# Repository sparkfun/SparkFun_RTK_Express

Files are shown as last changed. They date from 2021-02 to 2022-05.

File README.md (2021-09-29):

SparkFun RTK Express
===========================================================

SparkFun RTK Express (https://www.sparkfun.com/products/18442)

[*SparkFun RTK Express (GPS-18442)*](https://www.sparkfun.com/products/18442)

The SparkFun RTK Express is an easy to use GNSS receiver for centimeter-level positioning. Perfect for surveying, logging, and all types of post processing, this preprogrammed device can also be used for autonomous driving, navigation, asset tracking and any other application where there is a clear view of the sky. The RTK Express can also be used as a base station. With the press of a button, two RTK Expresses can be used to create an RTK system capable of 14mm horizontal positional accuracy. The built-in Bluetooth® connection via an ESP32 WROOM enables the user to use the RTK Express with their choice of GIS application on a phone or tablet. The built in battery allows for over five hours of field use and is compatible with common USB battery banks.

Repository Contents
-------------------

* **/Enclosure** - gcode for enclosure milling
* **/Graphics** - Bitmaps for the display
* **/Hardware** - Eagle files
* **/Overlay** - Design files for the adhesive membrane overlay

Documentation
--------------

* **[Hookup Guide](https://learn.sparkfun.com/tutorials/sparkfun-rtk-express-hookup-guide)** - Hookup guide for the SparkFun RTK Express.

License Information
-------------------

This product is _**open source**_!

Various bits of the code have different licenses applied. Anything SparkFun wrote is beerware; if you see me (or any other SparkFun employee) at the local, and you've found our code helpful, please buy us a round!

Please use, reuse, and modify these files as you see fit. Please maintain attribution to SparkFun Electronics and release anything derivative under the same license.

Distributed as-is; no warranty is given.

- Your friends at SparkFun.

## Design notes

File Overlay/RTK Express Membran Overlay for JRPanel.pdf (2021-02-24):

Please find the attached 1:1 PDF and AI files.

Membrane Switch

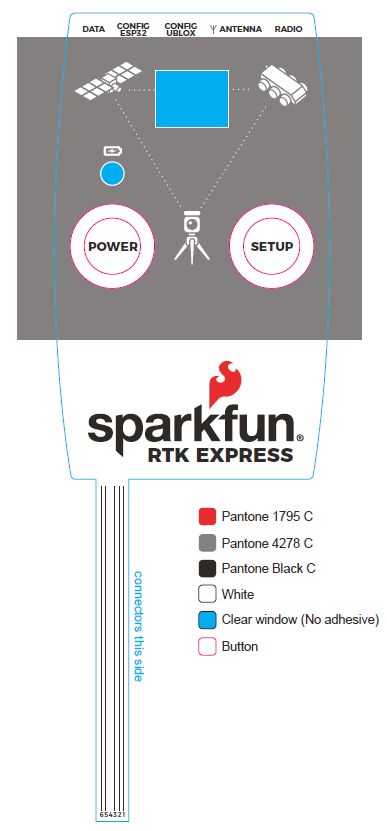
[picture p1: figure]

We need good UV protection as this device will be used outdoors.

Dimensions:
- ~160x80mm

Qty:
- 100pcs

Material:
- PC

Material Surface:
- Glossy Surface

Adhesive:
- We think we need 3M468 but welcome feedback.

Material Thickness:
- We think we need 0.175 but welcome feedback.

Color Quantity:
- 3

Top embossing:
- Yes

LED:
- Qty: 1
- What is the best method to diffuse the LED in a membrane overlay? Do you recommend the material over the LED be lightly painted?
- Color: Red
- Size: 1206

Buttons: (https://www.jrpanel.com/product/)
- Qty: 2
- Type: Die pressing
- Shape: “Flat embossed key”

Ribbon connector:
- Overall width: 6.5mm
- Only 5 conductors are needed

Windows:
- Yes

Cutting Method:
- Mould cutting

No gloss window with matte surface No light color process

No electrostatic shield

Ribbon connector detail:

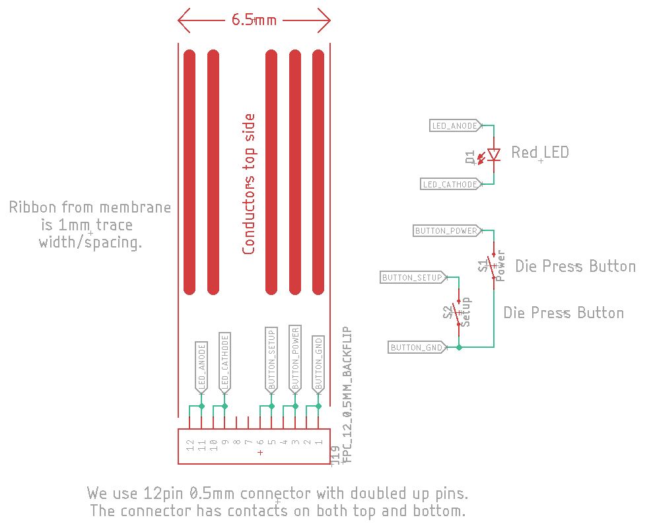
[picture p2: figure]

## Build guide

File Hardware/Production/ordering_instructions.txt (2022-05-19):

panel size, 220x136mm
PCB thickness, 1.6mm
number of layers, 4
controlled impedance, JLC7628
soldermask color, Red
silkscreen color, White
oz copper, 1oz
finish, ENIG
stencils, top+bottom
pcs per panel, 3
min trace width, 0.1778mm / 0.0070in
min drill size, 0.3048mm / 0.0120in
filename to layer stackup 1/2/3/4: GTL, GL2, GL3, GBL

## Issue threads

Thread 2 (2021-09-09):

Sparkfun RTK Express RTCM ver

BeniDodelson, 2021-09-09:
Hi,

I wonder if RTK Express supports RTCM ver 3.2 and/or what ver. it supports?

Tx.

nseidle, 2021-09-09:
See Default interface settings in the [integration manual](https://www.u-blox.com/sites/default/files/ZED-F9P_IntegrationManual_UBX-18010802.pdf)

> RTCM 3.3 is the default input and output protocol

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

BeniDodelson, 2021-09-10:
Tx. Nathan.

Appreciate your help.

Beni.

Beni Dodelson
G.P.Co. Trade Ltd.

20b Ha’Gome St.
POB 4187
Kadima
Israel 6092000

Tel : +972 - (0)54 - 5707979
Fax: +972 – (0) 9 – 8992284
E_mail :  ***@***.***> ***@***.***

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

Closed 2021-09-09.

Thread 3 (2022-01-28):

[sparkfun]RTK Express support

jblee94, 2022-01-28:
hello.

I'd like to ask you questions while using RTK after watching "RTK Express Hookup Guide".

1. What does "Mean" mean in the survey procedure at Base Station?
As a result of the test, if 30 satellites are used and move on to the survey procedure, "Mean" will be lowered to 0.7. (If "Time" is set to 600 seconds via S/W)

2. Configuration settings through serial connection.
Serial access, set "main menu" -> "3) configuration base" -> "3) set required mean 3D standard deviation: 5.000 meters" and then exit "main menu" and check the data in the base mode, and it appears as "waiting for horzacuracy < 2.00 meters".
Here, "waiting for horror <1.00" How can I change this part to a value other than "1.00"?

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

nseidle, 2022-01-31:
Hi,

1) Mean is to [average](https://www.mathsisfun.com/definitions/mean.html) across a set of numbers. On the RTK products, we use the recommended u-blox procedure: we take readings for 60s and until the mean (average) standard deviation is less than 5 meters. Increasing the survey time to 600s will marginally help accuracy of a temperary base, but I don't recommend it. If you need accuracy for your base, use a [fixed base](https://learn.sparkfun.com/tutorials/how-to-build-a-diy-gnss-reference-station/all#affix-your-antenna).

2) Before a survey begins, the RTK firmware waits for the current fix accuracy to be better than 1m. This is to prevent a unit entering survey mode directly from a power on hot start. If a survey begins with poor fix accuracy it will cause the standard mean to be very large, thus causing a survey to fail.

This 1.0m value cannot (currently) be changed and is by design. I am always open to adding more features if you can describe the situation where you need to modify this value.

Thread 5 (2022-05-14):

add another button to the overlay

mzandrew, 2022-05-14:
It would be nice to have an extra button (or two) for the interface.  Something to add the ability to mark multiple types of thing during a single survey (think button "A" for fenceposts vs button "B" for treestumps).  Or could mark the beginning and end of tracks (think press "A"; perambulate one's yard; press "A" again; move to backyard; repeat; end up with two tracks marking out yards).  Button "B" could close file and open another one to further aid in doing complicated surveys.

An extra button or two could also add functionality to various menus.

Looks like there's two spare pins on the connector that could be used, so one button probably wouldn't be a big deal to add (without forgoing the pin doubling or changing the connector type).  Would need to modify the main board to accommodate this of course.

nseidle, 2022-05-14:
Hi! Thanks for the idea contribution. For now we plan to keep the device as simple as possible and leave the user interactions to the tablet or cellphone to record points of interest.

Closed 2022-05-14.

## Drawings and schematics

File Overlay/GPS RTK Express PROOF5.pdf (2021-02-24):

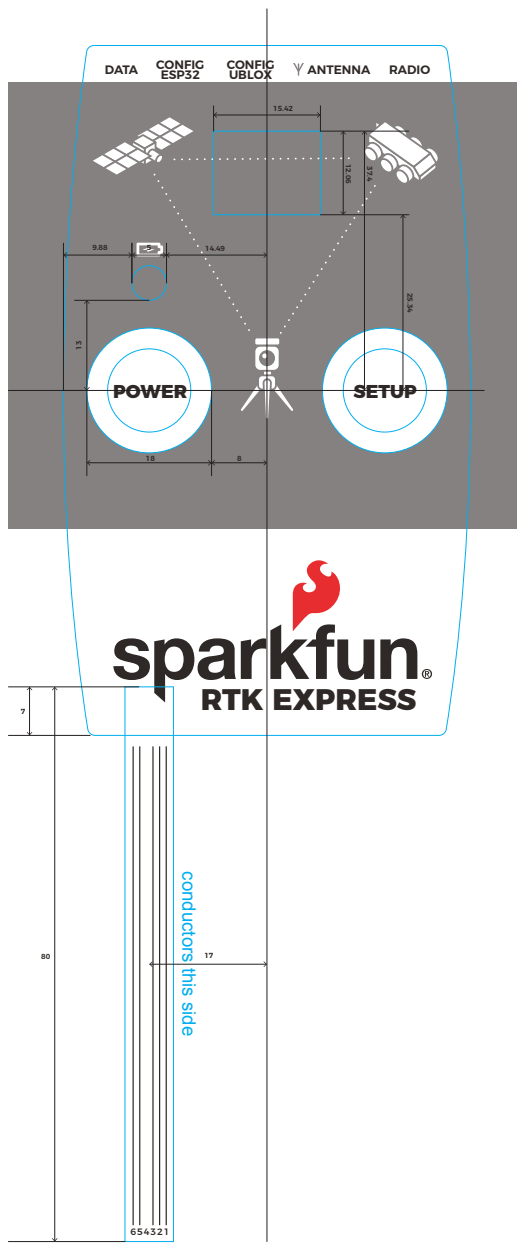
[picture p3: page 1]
DATA; CONFIG; UBLOX CONFIG; ESP32; ANTENNA RADIO; RTK EXPRESS; POWER; SETUP conductors this side

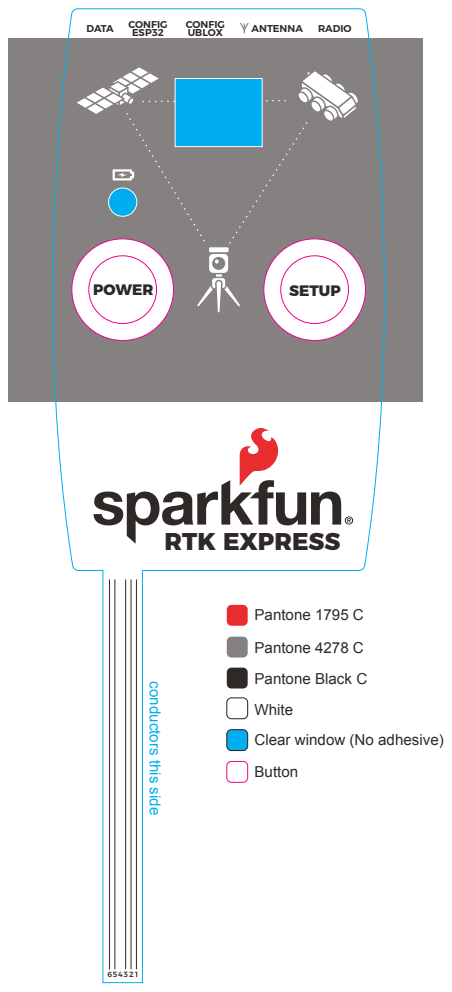
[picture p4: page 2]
DATA; CONFIG; UBLOX CONFIG; ESP32; ANTENNA RADIO; RTK EXPRESS; POWER; SETUP

Pantone 1795 C
Pantone 4278 C
Pantone Black C
White
Clear window (No adhesive)
Button

conductors this side

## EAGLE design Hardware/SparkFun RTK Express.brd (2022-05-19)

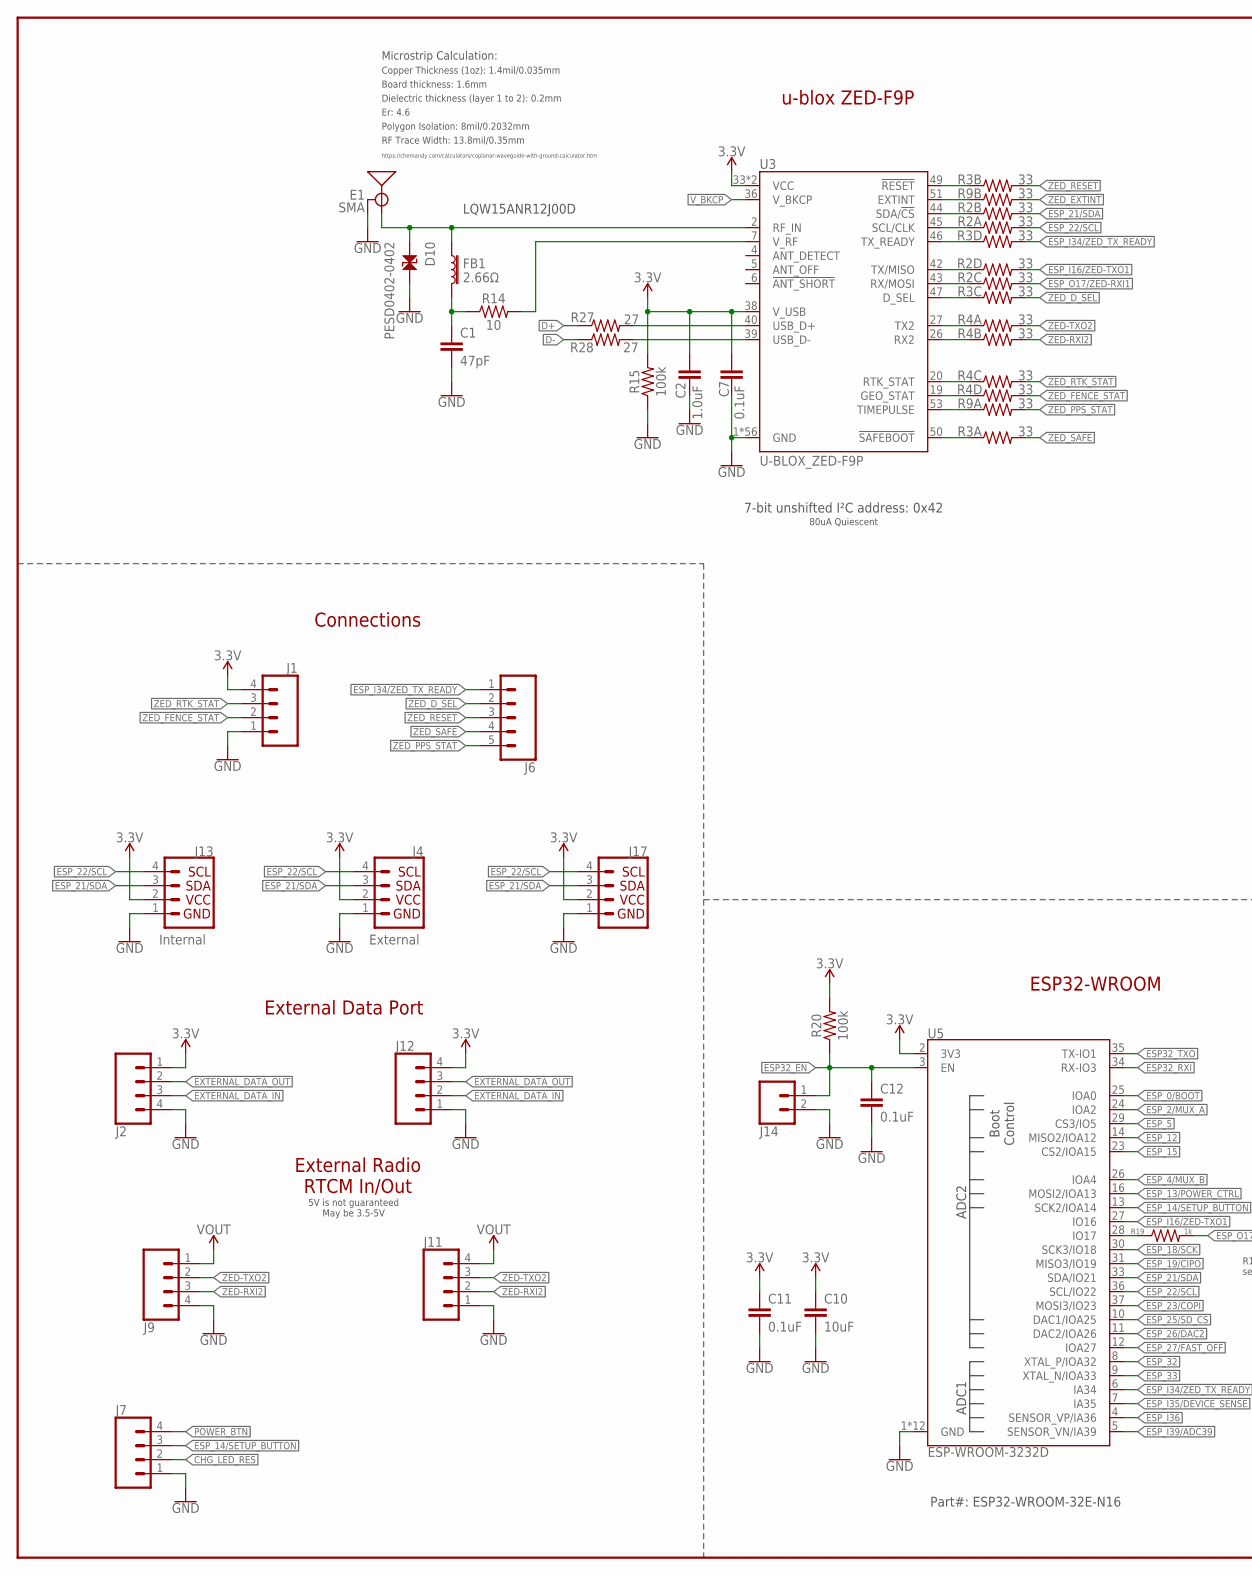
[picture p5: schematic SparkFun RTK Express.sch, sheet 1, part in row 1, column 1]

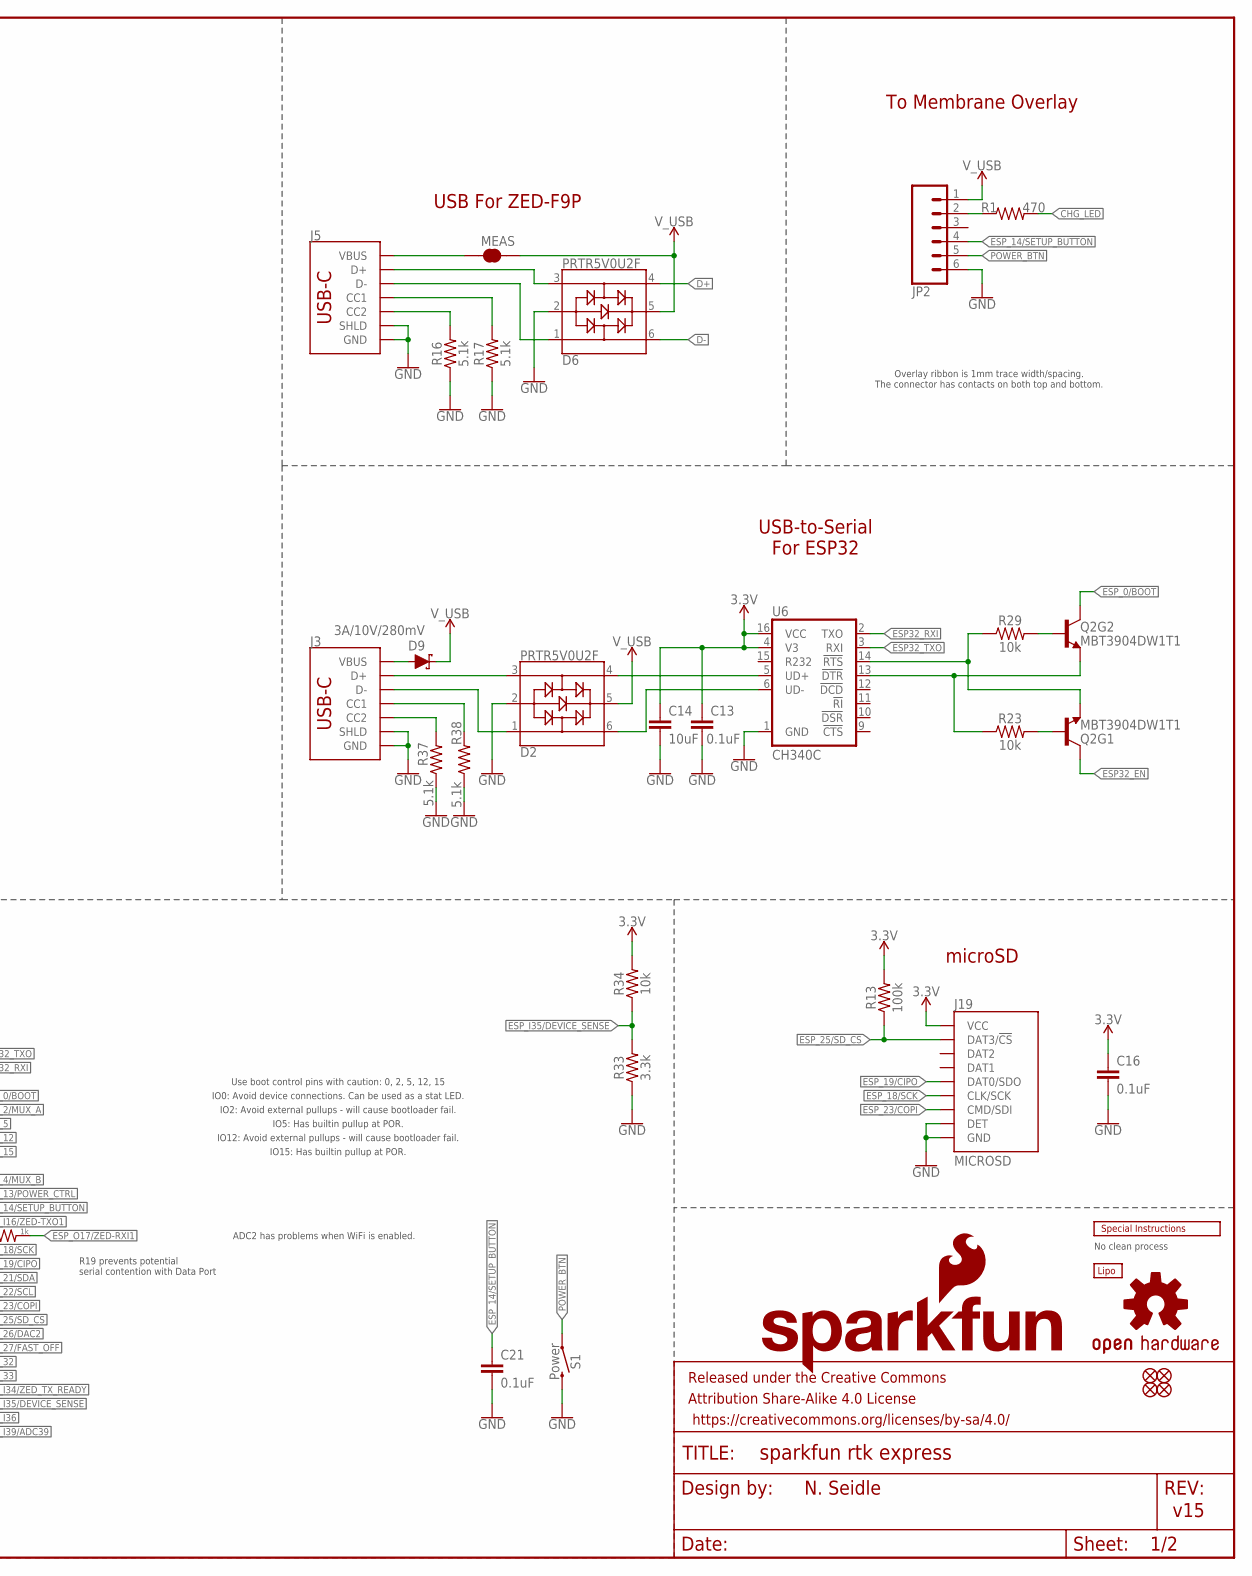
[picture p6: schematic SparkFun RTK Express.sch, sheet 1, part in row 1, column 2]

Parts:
BT1: LIPO-OUTLINE1000; LIPO-1000
C1: 47pF; 0402
C2: 1.0uF; 0603
C7, C11, C12, C13, C16, C21: 0.1uF; 0603
C10, C14: 10uF; 0603
D2, D6: PRTR5V0U2F; SOT886
D9: 3A/10V/280mV; SOD-323
D10: PESD0402-0402; 0402
E1: SMA; SMA-EDGE
FB1: 2.66Ω; 0402-TIGHT
FRAME2: FRAME-LEDGER; CREATIVE_COMMONS
J1, J7, J11, J12: CONN_041X04_NO_SILK_NO_POP; 1X04_NO_SILK
J2, J9: CONN_04JST-SMD-LOCKING; JST-4-SMD-1.25MM-LOCKING
J3, J5: USB Female Type C Connector; USB-C-16P_4LAYER-PADS
J4: External; JST04_1MM_RA
J6: CONN_05NO_SILK; 1X05_NO_SILK
J13: Internal; JST04_1MM_RA
J14: CONN_021X02_NO_SILK; 1X02_NO_SILK
J17: Qwiic Right Angle; 1X04_NO_SILK
J19: MICROSD; MICROSD-EXTERNALPIN
JP2: CONN_061MM-LIF; FPC_6_1MM-LIF
JP21, JP61, JP71, JP81: FIDUCIALUFIDUCIAL; FIDUCIAL-MICRO
LOGO1: OSHW-LOGOMINI; OSHW-LOGO-MINI
LOGO2: SFE_LOGO_NAME_FLAME.1_INCH; SFE_LOGO_NAME_FLAME_.1
MEAS: JUMPER-COMBO_2_NC_TRACE; COMBO-JUMPER_2_NC_TRACE
Q2: MBT3904DW1T1; SC70-6
R1: 470; 0603
R2, R3, R4, R9: 33; 1206_RA
R13, R15, R20: 100k; 0603
R14: 10; 0603
R16, R17, R37, R38: 5.1k; 0603
R19: 1k; 0603
R23, R29, R34: 10k; 0603
R27, R28: 27; 0603
R33: 3.3k; 0603
S1: Power; TACTILE_SWITCH_SMD_5.2MM
U3: U-BLOX_ZED-F9P; ZED-F9P
U5: ESP-WROOM-3232D; ESP-WROOM-32D
U6: CH340C; SO016
U$2: SPECIAL_INSTRUCTIONS-ORDERING; ORDERING_INSTRUCTIONS

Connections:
3.3V: C2.1, C7.2, C10.1, C11.1, C13.1, C14.1, C16.1, J1.4, J2.1, J4.2, J12.4, J13.2, J17.2, J19.4 (VCC), R13.2, R15.2, R20.2, R34.2, U3.33 (VCC), U3.34 (VCC), U3.38 (V_USB), U5.2 (3V3), U6.4 (V3), U6.16 (VCC); also elsewhere on the board
ANT_VCC: C1.1, FB1.2, R14.1
CC1: J5.A5 (CC1), R17.2
CC2: J5.B5 (CC2), R16.2
CC3: J3.B5 (CC2), R37.2
CC4: J3.A5 (CC1), R38.2
CHG_LED: R1.2; also elsewhere on the board
CHG_LED_RES: J7.2, JP2.2, R1.1
D+: D6.4, R27.1
D+1: D2.4, U6.5 (UD+)
D-: D6.6, R28.1
D-1: D2.6, U6.6 (UD-)
ESP32_!DTR: Q2.1 (E), R23.1, U6.13 (!DTR)
ESP32_!RTS: Q2.4 (E), R29.1, U6.14 (!RTS)
ESP32_EN: C12.1, J14.1, Q2.3 (C), R20.1, U5.3 (EN)
ESP32_RXI: U5.34 (RX-IO3), U6.2 (TXO)
ESP32_TXO: U5.35 (TX-IO1), U6.3 (RXI)
ESP_0/BOOT: Q2.6 (C), U5.25 (IOA0)
ESP_2/MUX_A: U5.24 (IOA2); also elsewhere on the board
ESP_4/MUX_B: U5.26 (IOA4); also elsewhere on the board
ESP_5: U5.29 (CS3/IO5)
ESP_12: U5.14 (MISO2/IOA12)
ESP_13/POWER_CTRL: U5.16 (MOSI2/IOA13); also elsewhere on the board
ESP_14/SETUP_BUTTON: C21.1, J7.3, JP2.4, U5.13 (SCK2/IOA14)
ESP_15: U5.23 (CS2/IOA15)
ESP_18/SCK: J19.5 (CLK/SCK), U5.30 (SCK3/IO18)
ESP_19/CIPO: J19.7 (DAT0/SDO), U5.31 (MISO3/IO19)
ESP_21/SDA: J4.3, J13.3, J17.3, R2.P7 (2), U5.33 (SDA/IO21); also elsewhere on the board
ESP_22/SCL: J4.4, J13.4, J17.4, R2.P8 (2), U5.36 (SCL/IO22); also elsewhere on the board
ESP_23/COPI: J19.3 (CMD/SDI), U5.37 (MOSI3/IO23)
ESP_25/SD_!CS!: J19.2 (DAT3/!CS!), R13.1, U5.10 (DAC1/IOA25)
ESP_26/DAC2: U5.11 (DAC2/IOA26); also elsewhere on the board
ESP_26/ZED_TX_READY_LV: R3.P4 (1), U3.46 (TX_READY)
ESP_27/FAST_OFF: U5.12 (IOA27); also elsewhere on the board
ESP_32: U5.8 (XTAL_P/IOA32)
ESP_33: U5.9 (XTAL_N/IOA33)
ESP_D1+: D2.3, J3.A6 (D+), J3.B6 (D+)
ESP_D1-: D2.1, J3.A7 (D-), J3.B7 (D-)
ESP_I16/ZED-TXO1: R2.P5 (2), U5.27 (IO16); also elsewhere on the board
ESP_I34/ZED_TX_READY: J6.1, R3.P5 (2), U5.6 (IA34)
ESP_I35/DEVICE_SENSE: R33.2, R34.1, U5.7 (IA35)
ESP_I36: U5.4 (SENSOR_VP/IA36)
ESP_I39/ADC39: U5.5 (SENSOR_VN/IA39); also elsewhere on the board
ESP_O17/ZED-RXI1: R2.P6 (2), R19.2; also elsewhere on the board
EXTERNAL_DATA_IN: J2.3, J12.2; also elsewhere on the board
EXTERNAL_DATA_OUT: J2.2, J12.3; also elsewhere on the board
EXTINT_LV: R9.P2 (1), U3.51 (EXTINT)
FENCE_LV: R4.P4 (1), U3.19 (GEO_STAT)
GND: C1.2, C2.2, C7.1, C10.2, C11.2, C12.2, C13.2, C14.2, C16.2, C21.2, D2.2, D6.2, D10.2, E1.GND@0 (GND), E1.GND@1 (GND), E1.GND@2 (GND), E1.GND@3 (GND), J1.1, J2.4, J3.GND, J3.GND2 (GND), J3.SHLD1 (SHLD), J3.SHLD2 (SHLD), J3.SHLD3 (SHLD), J3.SHLD4 (SHLD), J4.1, J5.GND, J5.GND2 (GND), J5.SHLD1 (SHLD), J5.SHLD2 (SHLD), J5.SHLD3 (SHLD), J5.SHLD4 (SHLD), J7.1, J9.4, J11.1, J12.1, J13.1, J14.2, J17.1, J19.6 (GND), J19.9 (DET), J19.10 (GND), J19.11 (GND), J19.12 (GND), J19.13 (GND), JP2.6, R15.1, R16.1, R17.1, R33.1, R37.1, R38.1, S1.3 (2), U3.1 (GND), U3.3 (GND), U3.12 (GND), U3.14 (GND), U3.32 (GND), U3.37 (GND), U3.41 (GND), U3.48 (GND), U3.55 (GND), U3.56 (GND), U3.57 (GND), U3.58 (GND), U3.59 (GND), U3.60 (GND), U3.61 (GND), U3.62 (GND), U3.63 (GND), U3.64 (GND), U3.65 (GND), U3.66 (GND), U3.67 (GND), U3.68 (GND), U3.69 (GND), U3.70 (GND), U3.71 (GND), U3.72 (GND), U3.73 (GND), U3.74 (GND), U3.75 (GND), U3.76 (GND), U3.77 (GND), U3.78 (GND), U3.79 (GND), U3.80 (GND), U3.81 (GND), U3.82 (GND), U3.83 (GND), U3.84 (GND), U3.85 (GND), U3.86 (GND), U3.87 (GND), U3.88 (GND), U3.89 (GND), U3.90 (GND), U3.91 (GND), U3.92 (GND), U3.93 (GND), U3.94 (GND), U3.95 (GND), U3.96 (GND), U3.97 (GND), U3.98 (GND), U3.99 (GND), U3.100 (GND), U3.101 (GND), U3.102 (GND), U5.1 (GND), U5.15 (GND), U5.38 (GND), U5.GND, U5.GNDT1 (GND), U5.GNDT2 (GND), U5.GNDT3 (GND), U5.GNDT4 (GND), U5.GNDT5 (GND), U5.GNDT6 (GND), U5.GNDT7 (GND), U5.GNDT8 (GND), U6.1 (GND); also elsewhere on the board
GPS_ANT1: D10.1, E1.SIG (SIGNAL), FB1.1, U3.2 (RF_IN)
unnamed: J5.VBUS1 (VBUS), J5.VBUS2 (VBUS), MEAS.1, MEAS.3 (1)
unnamed: R19.1, U5.28 (IO17)
unnamed: R27.2, U3.40 (USB_D+)
unnamed: R28.2, U3.39 (USB_D-)
unnamed: R14.2, U3.7 (V_RF)
unnamed: Q2.5 (B), R23.2
unnamed: Q2.2 (B), R29.2
unnamed: D9.A, J3.VBUS1 (VBUS), J3.VBUS2 (VBUS)
POWER_BTN: J7.4, JP2.5, S1.1; also elsewhere on the board
PPS: R9.P1 (1), U3.53 (TIMEPULSE)
RTK_LV: R4.P3 (1), U3.20 (RTK_STAT)
RX2_LV: R4.P2 (1), U3.26 (RX2)
RXLV: R2.P3 (1), U3.43 (RX/MOSI)
SCL_LV: R2.P1 (1), U3.45 (SCL/CLK)
SDA_LV: R2.P2 (1), U3.44 (SDA/!CS!)
TX2_LV: R4.P1 (1), U3.27 (TX2)
TXLV: R2.P4 (1), U3.42 (TX/MISO)
UNP_D+: D6.3, J5.A6 (D+), J5.B6 (D+)
UNP_D-: D6.1, J5.A7 (D-), J5.B7 (D-)
VOUT: J9.1, J11.4; also elsewhere on the board
V_BKCP: U3.36 (V_BKCP); also elsewhere on the board
V_USB: D2.5, D6.5, D9.C, JP2.1, MEAS.2, MEAS.4 (2); also elsewhere on the board
ZED-RXI2: J9.3, J11.2, R4.P7 (2)
ZED-TXO2: J9.2, J11.3, R4.P8 (2)
ZED_!RESET!: J6.3, R3.P7 (2)
ZED_!RESET!_LV: R3.P2 (1), U3.49 (!RESET!)
ZED_!SAFE!: J6.4, R3.P8 (2)
ZED_!SAFE!_LV: R3.P1 (1), U3.50 (!SAFEBOOT!)
ZED_D_SEL: J6.2, R3.P6 (2)
ZED_D_SEL_LV: R3.P3 (1), U3.47 (D_SEL)
ZED_EXTINT: R9.P7 (2); also elsewhere on the board
ZED_FENCE_STAT: J1.2, R4.P5 (2)
ZED_PPS_STAT: J6.5, R9.P8 (2); also elsewhere on the board
ZED_RTK_STAT: J1.3, R4.P6 (2)

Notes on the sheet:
v15
7-bit unshifted I²C address: 0x42
u-blox ZED-F9P
LQW15ANR12J00D
Board thickness: 1.6mm
Er: 4.6
Copper Thickness (1oz): 1.4mil/0.035mm
RF Trace Width: 13.8mil/0.35mm
Polygon Isolation: 8mil/0.2032mm
No clean process
Dielectric thickness (layer 1 to 2): 0.2mm
https://chemandy.com/calculators/coplanar-waveguide-with-ground-calculator.htm
Microstrip Calculation:
Connections
External Radio RTCM In/Out
External Data Port
ESP32-WROOM
USB-to-Serial For ESP32
microSD
5V is not guaranteed May be 3.5-5V
USB For ZED-F9P
N. Seidle
R19 prevents potential serial contention with Data Port
80uA Quiescent
To Membrane Overlay
Overlay ribbon is 1mm trace width/spacing. The connector has contacts on both top and bottom.
IO0: Avoid device connections. Can be used as a stat LED.
ADC2 has problems when WiFi is enabled.
IO12: Avoid external pullups - will cause bootloader fail.
Use boot control pins with caution: 0, 2, 5, 12, 15
IO2: Avoid external pullups - will cause bootloader fail.
IO15: Has builtin pullup at POR.
IO5: Has builtin pullup at POR.
Part#: ESP32-WROOM-32E-N16

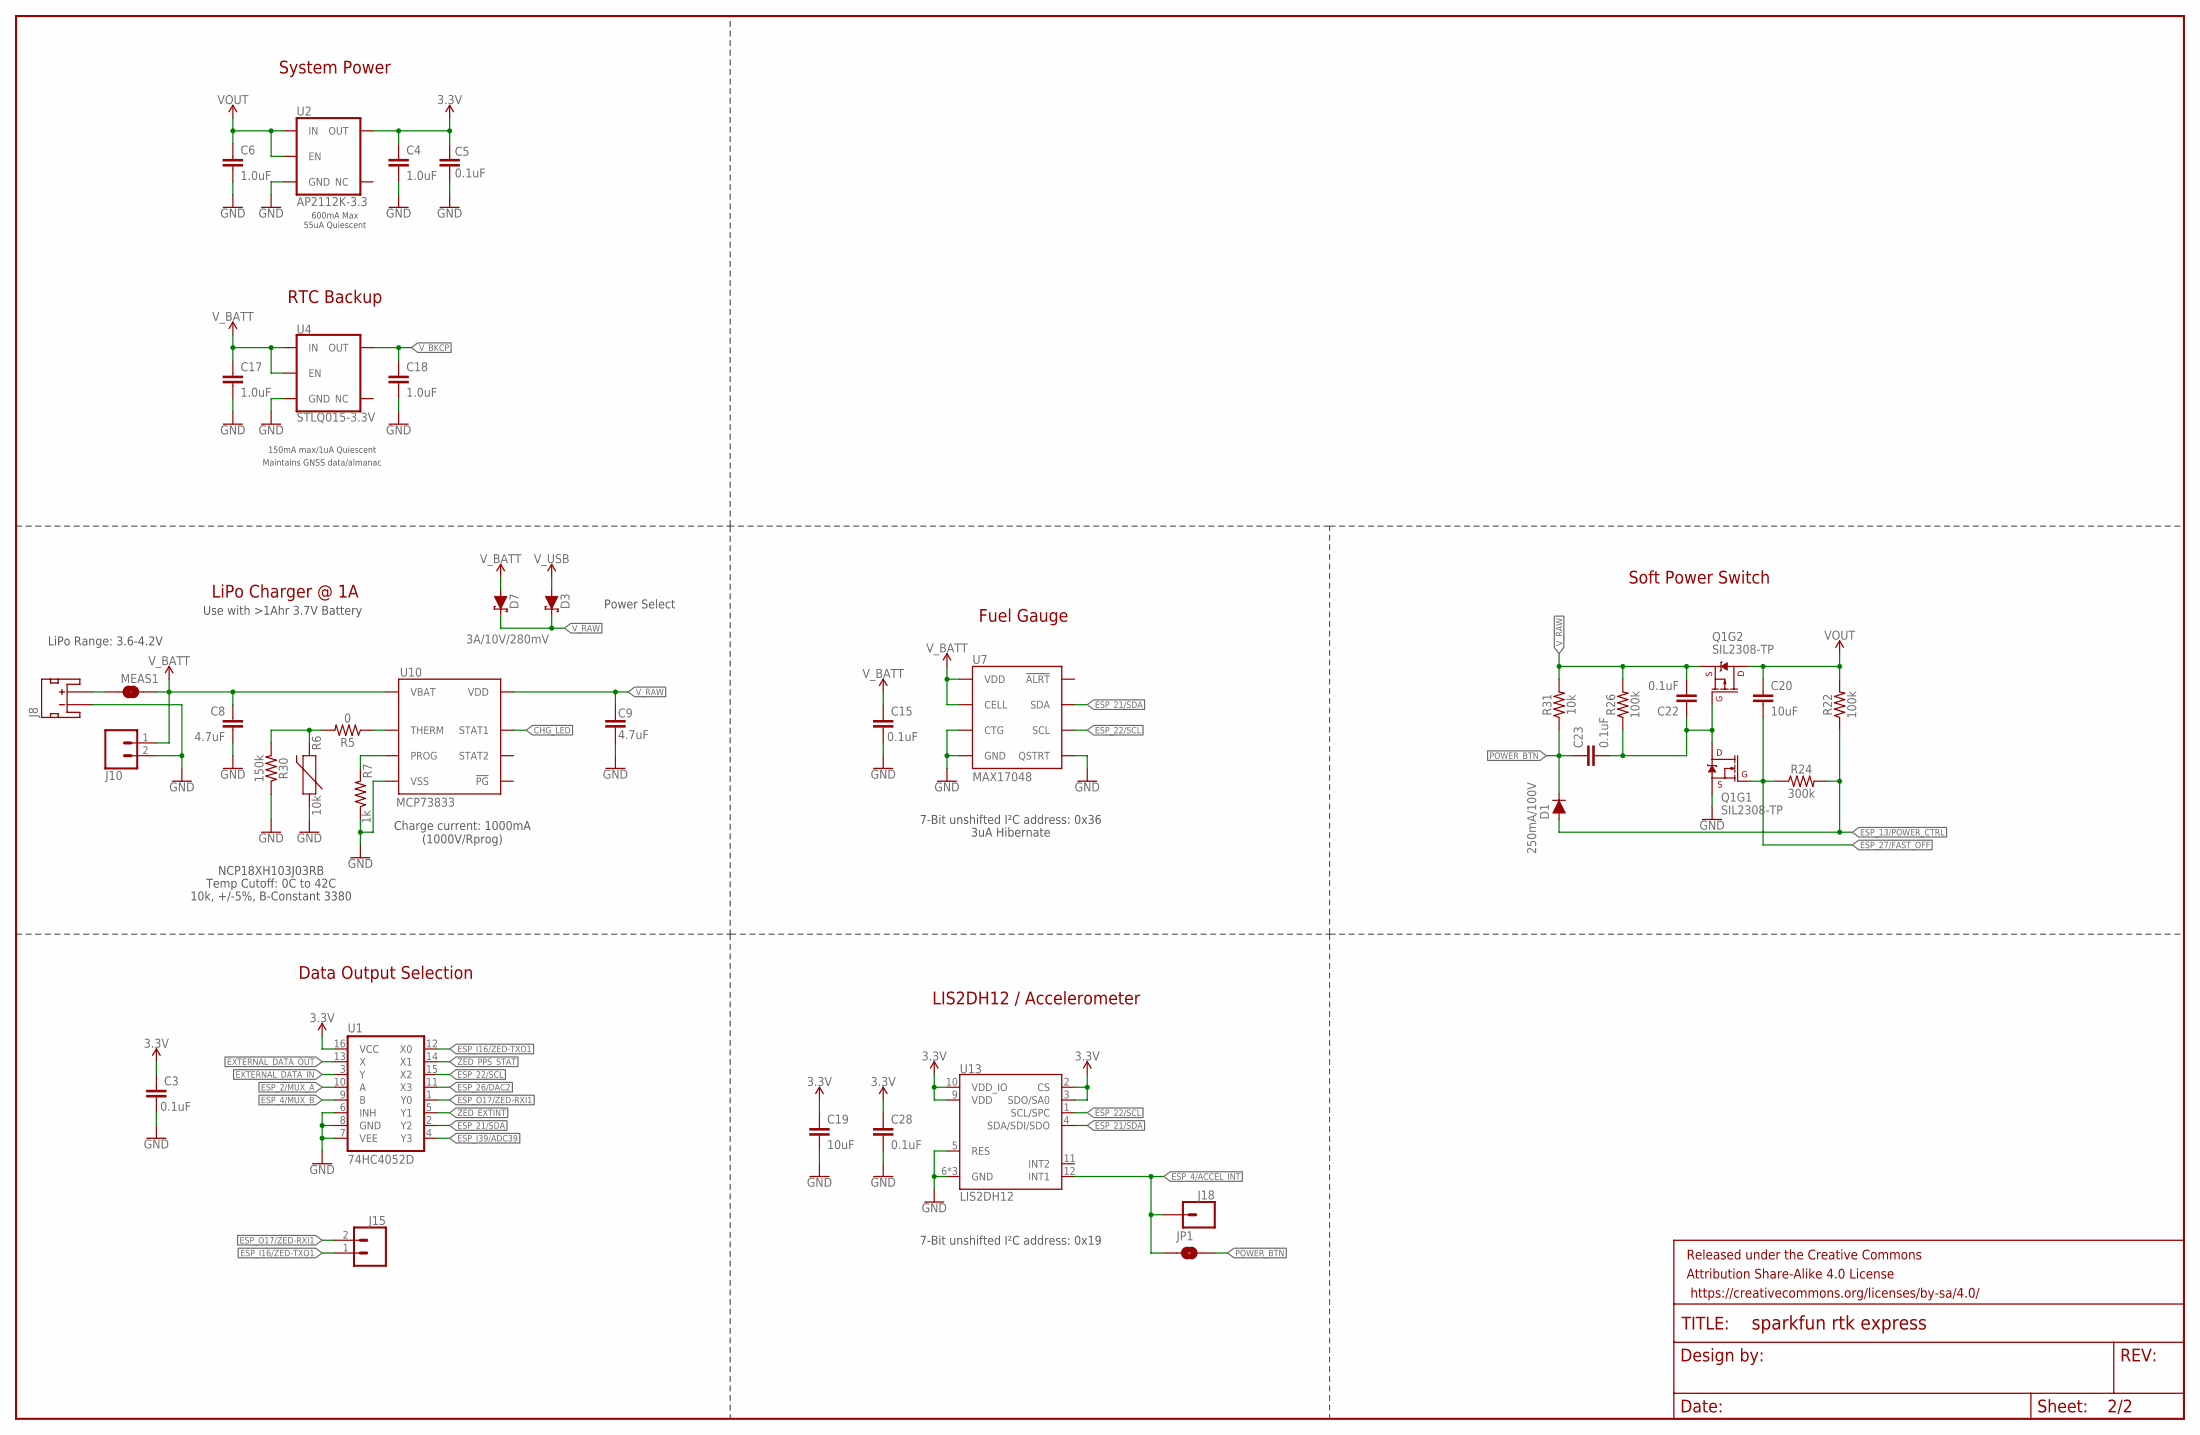
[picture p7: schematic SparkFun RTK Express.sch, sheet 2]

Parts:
C3, C5, C15, C22, C23, C28: 0.1uF; 0603
C4, C6, C17, C18: 1.0uF; 0603
C8, C9: 4.7uF; 0603
C19, C20: 10uF; 0603
D1: 250mA/100V; SOD-323
D3, D7: 3A/10V/280mV; SOD-323
FRAME3: FRAME-LEDGERNO_FOOTPRINT; DUMMY
J8: JST_2MM_MALE; JST-2-SMD
J10, J15: CONN_021X02_NO_SILK; 1X02_NO_SILK
J18: CONN_01PTH_NO_SILK_YES_STOP; 1X01_NO_SILK
JP1: JUMPER-SMT_2_NO_SILK; SMT-JUMPER_2_NO_SILK
MEAS1: JUMPER-COMBO_2_NC_TRACE; COMBO-JUMPER_2_NC_TRACE
Q1: SIL2308-TP; SOT26
R5: 0; 0603
R6, R31: 10k; 0603
R7: 1k; 0603
R22, R26: 100k; 0603
R24: 300k; 0603
R30: 150k; 0603
U1: 74HC4052D; SO16
U2: AP2112K-3.3; SOT23-5
U4: STLQ015-3.3V; SOT23-5
U7: MAX17048; DFN-8
U10: MCP73833; DFN-10
U13: LIS2DH12; LGA-12-LISDH12

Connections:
3.3V: C3.1, C4.1, C5.2, C19.1, C28.1, U1.16 (VCC), U2.5 (OUT), U13.2 (CS), U13.3 (SDO/SA0), U13.9 (VDD), U13.10 (VDD_IO); also elsewhere on the board
CHG_LED: U10.3 (STAT1); also elsewhere on the board
CHG_THERM1: R5.2, R6.2, R30.2
ESP_2/MUX_A: U1.10 (A); also elsewhere on the board
ESP_4/ACCEL_INT: J18.1, JP1.1, U13.12 (INT1)
ESP_4/MUX_B: U1.9 (B); also elsewhere on the board
ESP_13/POWER_CTRL: D1.A, R22.1, R24.2; also elsewhere on the board
ESP_21/SDA: U1.2 (Y2), U7.8 (SDA), U13.4 (SDA/SDI/SDO); also elsewhere on the board
ESP_22/SCL: U1.15 (X2), U7.7 (SCL), U13.1 (SCL/SPC); also elsewhere on the board
ESP_26/DAC2: U1.11 (X3); also elsewhere on the board
ESP_27/FAST_OFF: C20.2, Q1.G1 (G), R24.1; also elsewhere on the board
ESP_I16/ZED-TXO1: J15.1, U1.12 (X0); also elsewhere on the board
ESP_I39/ADC39: U1.4 (Y3); also elsewhere on the board
ESP_O17/ZED-RXI1: J15.2, U1.1 (Y0); also elsewhere on the board
EXTERNAL_DATA_IN: U1.3 (Y); also elsewhere on the board
EXTERNAL_DATA_OUT: U1.13 (X); also elsewhere on the board
GND: C3.2, C4.2, C5.1, C6.2, C8.2, C9.2, C15.2, C17.2, C18.2, C19.2, C28.2, J8.1 (-), J10.2, Q1.S1 (S), R6.1, R7.1, R30.1, U1.6 (INH), U1.7 (VEE), U1.8 (GND), U2.2 (GND), U4.2 (GND), U7.1 (CTG), U7.4 (GND), U7.6 (QSTRT), U7.9 (GND), U10.5 (VSS), U10.11 (VSS), U13.5 (RES), U13.6 (GND), U13.7 (GND), U13.8 (GND); also elsewhere on the board
LIPO_RAW: J8.2 (+), MEAS1.1, MEAS1.3 (1)
unnamed: R5.1, U10.8 (THERM)
unnamed: C22.1, C23.2, Q1.D1 (D), Q1.G2 (G), R26.1
POWER_BTN: C23.1, D1.C, JP1.2, R31.1; also elsewhere on the board
PROG1: R7.2, U10.6 (PROG)
VOUT: C6.1, C20.1, Q1.D2 (D), R22.2, U2.1 (IN), U2.3 (EN); also elsewhere on the board
V_BATT: C8.1, C15.1, C17.1, D7.A, J10.1, MEAS1.2, MEAS1.4 (2), U4.1 (IN), U4.3 (EN), U7.2 (CELL), U7.3 (VDD), U10.9 (VBAT), U10.10 (VBAT)
V_BKCP: C18.1, U4.5 (OUT); also elsewhere on the board
V_RAW: C9.1, C22.2, D3.C, D7.C, Q1.S2 (S), R26.2, R31.2, U10.1 (VDD), U10.2 (VDD)
V_USB: D3.A; also elsewhere on the board
ZED_EXTINT: U1.5 (Y1); also elsewhere on the board
ZED_PPS_STAT: U1.14 (X1); also elsewhere on the board

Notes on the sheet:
LiPo Range: 3.6-4.2V
Charge current: 1000mA (1000V/Rprog)
Use with >1Ahr 3.7V Battery
LiPo Charger @ 1A
NCP18XH103J03RB
10k, +/-5%, B-Constant 3380
Temp Cutoff: 0C to 42C
Fuel Gauge
Data Output Selection
Power Select
3uA Hibernate
7-Bit unshifted I²C address: 0x19
LIS2DH12 / Accelerometer
Soft Power Switch
RTC Backup
System Power
600mA Max 55uA Quiescent
150mA max/1uA Quiescent
Maintains GNSS data/almanac
7-Bit unshifted I²C address: 0x36

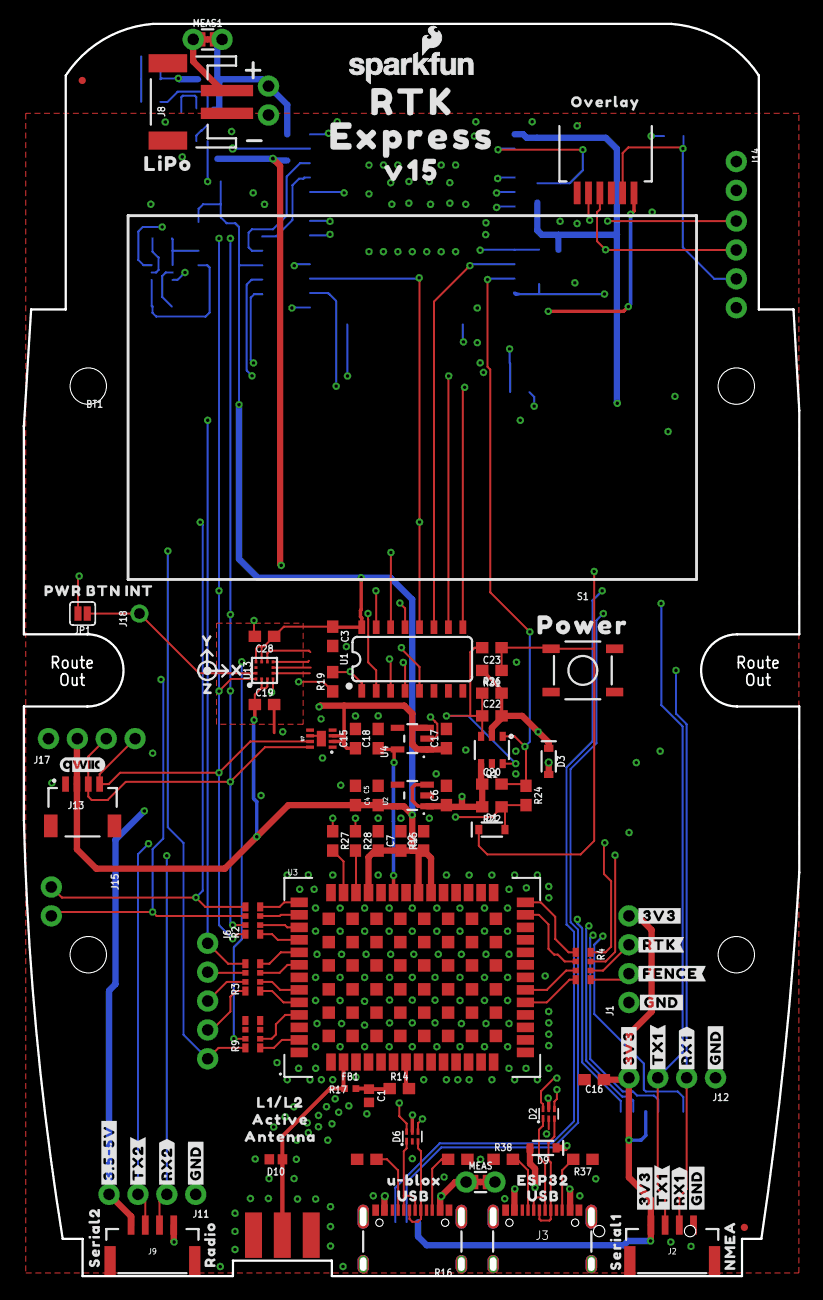
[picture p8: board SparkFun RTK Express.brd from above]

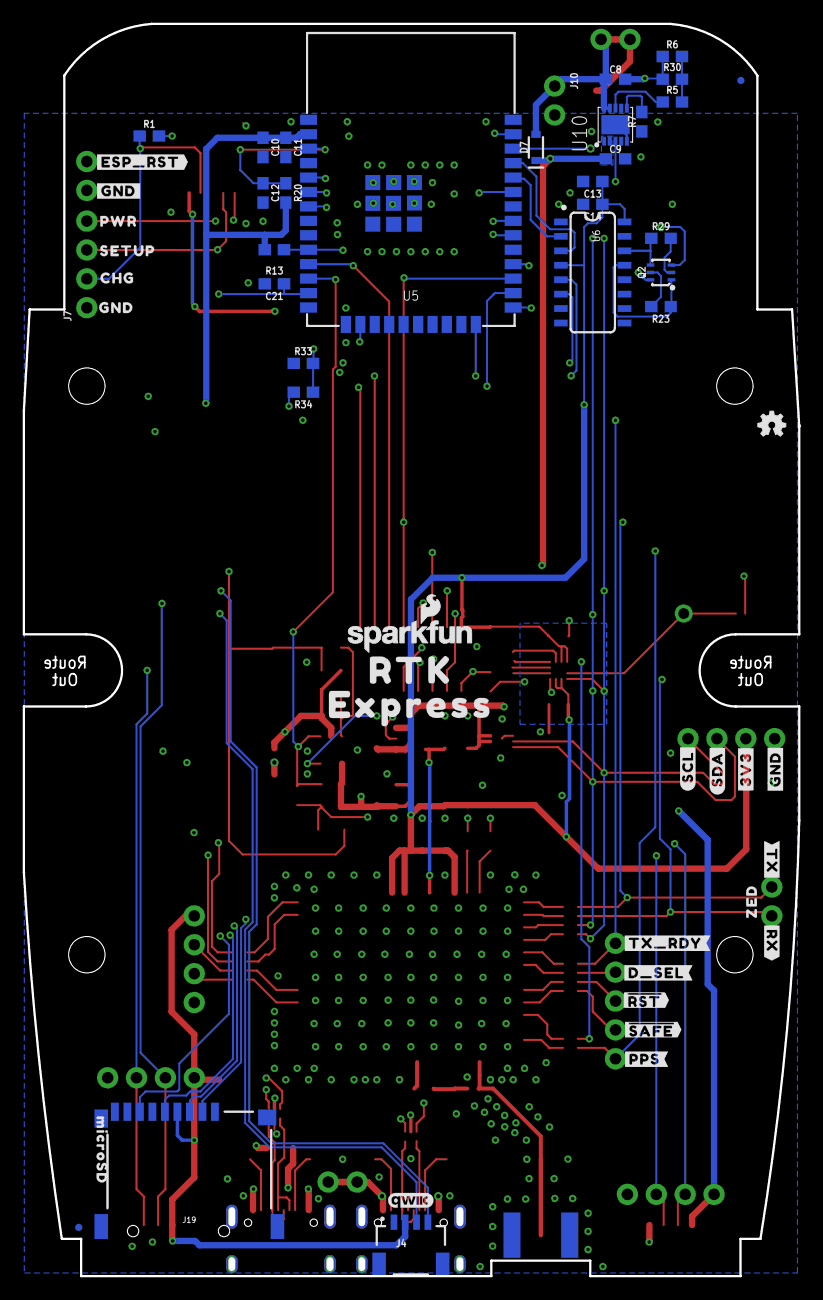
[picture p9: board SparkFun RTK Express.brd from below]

Board: 4 copper layers, 68.2 x 110.1 mm, 168 parts (54 on the bottom side), 86 nets.

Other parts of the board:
LOGO3: SFE_LOGO_NAME_FLAME.1_INCH; SFE_LOGO_NAME_FLAME_.1
U$1, U$38, U$48, U$82: #GND#0
U$3: #TX_RDY#0
U$4: INT0
U$5, U$37, U$47: #3V3#0
U$6: L1#L20
U$7, U$74: RTK0
U$8: OVERLAY0
U$9: PWR_BTN1
U$10: #RTK#1
U$11: #PPS#0
U$13: ACTIVE1
U$14: #RX#2
U$15: ANTENNA2
U$16: ZED0
U$17: ##SAFE##5
U$18: V150
U$23: #3#5#5V#0
U$24: X0
U$26: 1553DBK-ENCLOSURE
U$27: LIPO0
U$28: ##RST##4
U$29: SERIAL10
U$30, U$93: QWIIC_4MM
U$31: POWER0
U$32: #FENCE#3
U$33: CHG2
U$34: GND3
U$35: U#BLOX0
U$36, U$66: USB1
U$39: #RX2#2
U$40: #TX2#1
U$41: PWR0
U$42: SETUP1
U$43: SERIAL20
U$45, U$68: #RX1#2
U$46, U$65: #TX1#1
U$49: NMEA1
U$50: RADIO0
U$51, U$53: EXPRESS0
U$55: Y1
U$56: Z2
U$60: #ESP_RST#0
U$67: ESP320
U$70: #GND#2
U$72: #TX#1
U$83: MICROSD0
U$84: #GND#1
U$85: #3V3#2
U$86: #SCL#1
U$87: #SDA#0
U$88: #D_SEL#0

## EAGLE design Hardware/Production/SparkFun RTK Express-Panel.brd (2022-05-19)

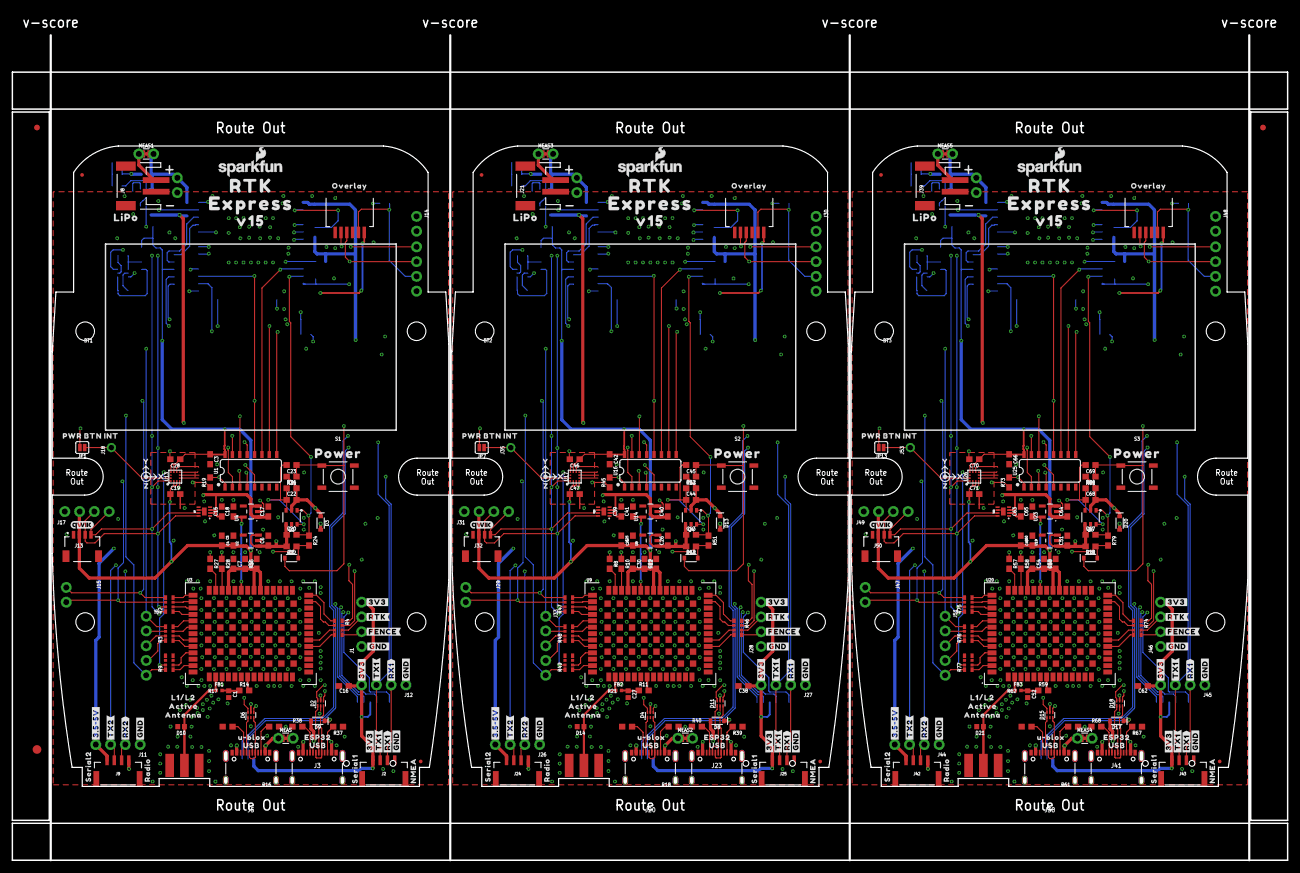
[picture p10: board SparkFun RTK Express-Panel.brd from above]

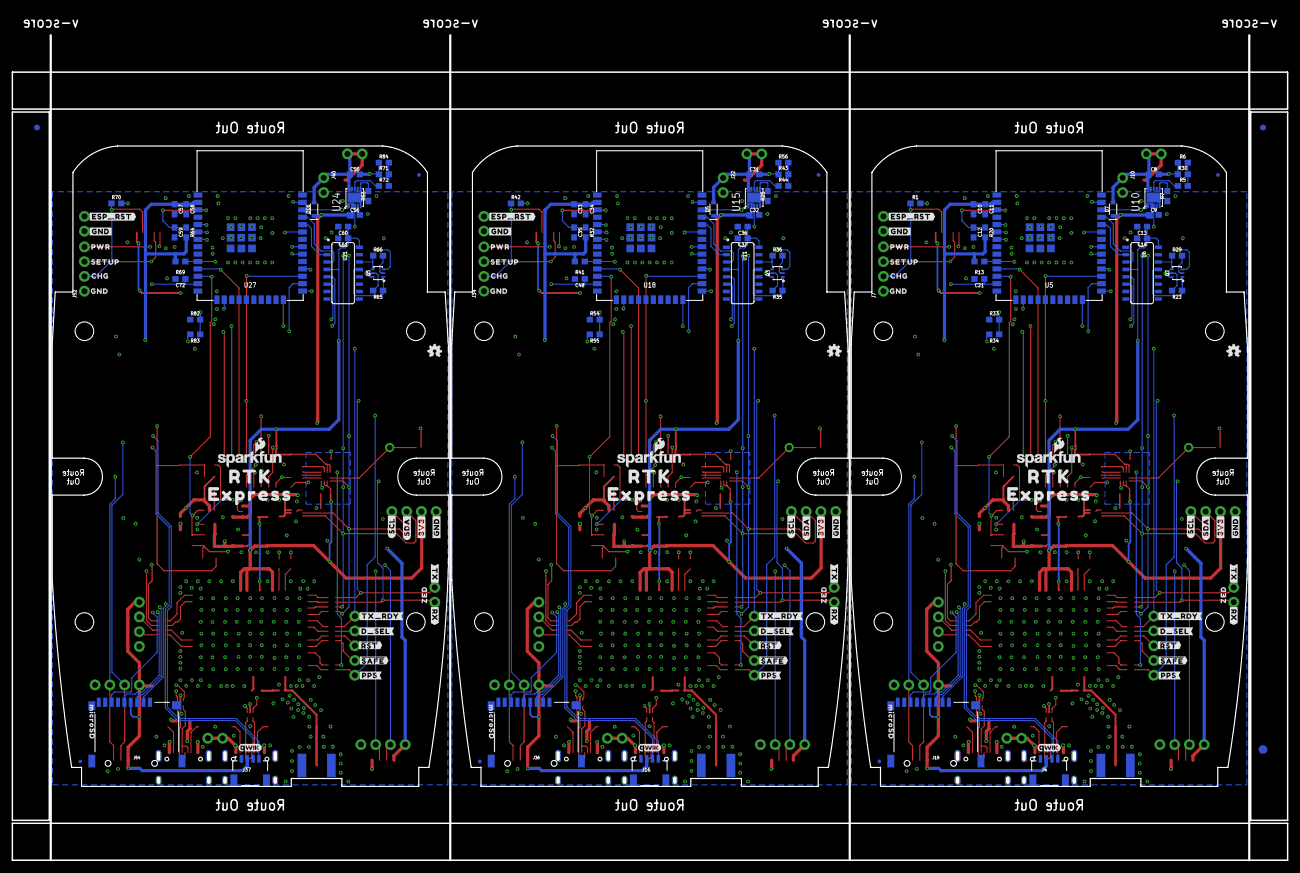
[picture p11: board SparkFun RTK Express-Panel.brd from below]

Board: 4 copper layers, 219.3 x 141.9 mm, 501 parts (165 on the bottom side), 258 nets.

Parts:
BT1, BT2, BT3: LIPO-OUTLINE1000; LIPO-1000
C1, C27, C52: 47pF; 0402
C2, C4, C6, C17, C18, C24, C26, C29, C40, C41, C49, C51, C53, C64, C65: 1.0uF; 0603
C3, C5, C7, C11, C12, C13, C15, C16, C21, C22, C23, C25, C28, C30, C34, C35, C36, C38, C39, C42, C44, C45, C46, C48, C50, C54, C58, C59, C60, C62, C63, C66, C68, C69, C70, C72: 0.1uF; 0603
C8, C9, C31, C32, C55, C56: 4.7uF; 0603
C10, C14, C19, C20, C33, C37, C43, C47, C57, C61, C67, C71: 10uF; 0603
D1, D12, D19: 250mA/100V; SOD-323
D2, D4, D6, D11, D15, D18: PRTR5V0U2F; SOT886
D3, D5, D7, D8, D9, D13, D16, D17, D20: 3A/10V/280mV; SOD-323
D10, D14, D21: PESD0402-0402; 0402
E1, E2, E3: SMA; SMA-EDGE
E$1, E$2, E$3, E$4: FIDUCIAL-1X2
E$5, E$6: FIDUCIAL-1.5X3
FB1, FB2, FB3: 2.66Ω; 0402-TIGHT
J1, J7, J11, J12, J26, J27, J28, J34, J44, J45, J46, J52: 1X04_NO_SILK
J2, J9, J24, J25, J42, J43: JST-4-SMD-1.25MM-LOCKING
J3, J5, J20, J23, J38, J41: USB Female Type C Connector; USB-C-16P_4LAYER-PADS
J4, J16, J37: External; JST04_1MM_RA
J6, J33, J51: 1X05_NO_SILK
J8, J21, J39: JST-2-SMD
J10, J14, J15, J22, J29, J30, J40, J47, J48: 1X02_NO_SILK
J13, J32, J50: Internal; JST04_1MM_RA
J17, J31, J49: Qwiic Right Angle; 1X04_NO_SILK
J18, J35, J53: 1X01_NO_SILK
J19, J36, J54: MICROSD; MICROSD-EXTERNALPIN
JP1, JP7, JP13: JUMPER-SMT_2_NO_SILK; SMT-JUMPER_2_NO_SILK
JP2, JP8, JP14: FPC_6_1MM-LIF
JP3, JP4, JP5, JP6, JP9, JP10, JP11, JP12, JP21, JP61, JP71, JP81: FIDUCIALUFIDUCIAL; FIDUCIAL-MICRO
LOGO1, LOGO4, LOGO7: OSHW-LOGOMINI; OSHW-LOGO-MINI
LOGO2, LOGO3, LOGO5, LOGO6, LOGO8, LOGO9: SFE_LOGO_NAME_FLAME.1_INCH; SFE_LOGO_NAME_FLAME_.1
MEAS, MEAS1, MEAS2, MEAS3, MEAS4, MEAS5: COMBO-JUMPER_2_NC_TRACE
Q1, Q4, Q6: SIL2308-TP; SOT26
Q2, Q3, Q5: MBT3904DW1T1; SC70-6
R1, R42, R70: 470; 0603
R2, R3, R4, R9, R46, R47, R48, R49, R74, R75, R76, R77: 33; 1206_RA
R5, R44, R72: 0; 0603
R6, R23, R29, R31, R34, R35, R36, R53, R55, R56, R65, R66, R81, R83, R84: 10k; 0603
R7, R19, R25, R45, R63, R73: 1k; 0603
R8, R10, R27, R28, R57, R58: 27; 0603
R11, R14, R59: 10; 0603
R12, R13, R15, R20, R22, R26, R32, R41, R50, R52, R60, R64, R69, R78, R80: 100k; 0603
R16, R17, R18, R21, R37, R38, R39, R40, R61, R62, R67, R68: 5.1k; 0603
R24, R51, R79: 300k; 0603
R30, R43, R71: 150k; 0603
R33, R54, R82: 3.3k; 0603
S1, S2, S3: Power; TACTILE_SWITCH_SMD_5.2MM
U1, U16, U25: 74HC4052D; SO16
U2, U8, U19: AP2112K-3.3; SOT23-5
U3, U9, U20: U-BLOX_ZED-F9P; ZED-F9P
U4, U14, U23: STLQ015-3.3V; SOT23-5
U5, U18, U27: ESP-WROOM-3232D; ESP-WROOM-32D
U6, U11, U21: CH340C; SO016
U7, U12, U22: MAX17048; DFN-8
U10, U15, U24: MCP73833; DFN-10
U13, U17, U26: LIS2DH12; LGA-12-LISDH12
U$1, U$19, U$38, U$48, U$63, U$64, U$82, U$95, U$127, U$140, U$141, U$157: #GND#0
U$2, U$30, U$93, U$106, U$125, U$168: QWIIC_4MM
U$3, U$107, U$169: #TX_RDY#0
U$4, U$118, U$180: INT0
U$5, U$12, U$37, U$47, U$62, U$91, U$126, U$139, U$154: #3V3#0
U$6, U$121, U$183: L1#L20
U$7, U$74, U$99, U$100, U$161, U$162: RTK0
U$8, U$120, U$182: OVERLAY0
U$9, U$119, U$181: PWR_BTN1
U$10, U$20, U$128: #RTK#1
U$11, U$78, U$148: #PPS#0
U$13, U$122, U$184: ACTIVE1
U$14, U$79, U$149: #RX#2
U$15, U$123, U$185: ANTENNA2
U$16, U$80, U$150: ZED0
U$17, U$75, U$145: ##SAFE##5
U$18, U$124, U$186: V150
U$21, U$26, U$129: 1553DBK-ENCLOSURE
U$22, U$27, U$130: LIPO0
U$23, U$77, U$147: #3#5#5V#0
U$24, U$115, U$177: X0
U$25, U$35, U$131: U#BLOX0
U$28, U$73, U$144: ##RST##4
U$29, U$54, U$134: SERIAL10
U$31, U$108, U$170: POWER0
U$32, U$76, U$146: #FENCE#3
U$33, U$109, U$171: CHG2
U$34, U$110, U$172: GND3
U$36, U$44, U$66, U$89, U$132, U$152: USB1
U$39, U$57, U$135: #RX2#2
U$40, U$58, U$136: #TX2#1
U$41, U$111, U$173: PWR0
U$42, U$112, U$174: SETUP1
U$43, U$52, U$133: SERIAL20
U$45, U$59, U$68, U$94, U$137, U$156: #RX1#2
U$46, U$61, U$65, U$92, U$138, U$155: #TX1#1
U$49, U$69, U$142: NMEA1
U$50, U$71, U$143: RADIO0
U$51, U$53, U$113, U$114, U$175, U$176: EXPRESS0
U$55, U$116, U$178: Y1
U$56, U$117, U$179: Z2
U$60, U$98, U$160: #ESP_RST#0
U$67, U$90, U$153: ESP320
U$70, U$101, U$163: #GND#2
U$72, U$81, U$151: #TX#1
U$83, U$96, U$158: MICROSD0
U$84, U$97, U$159: #GND#1
U$85, U$102, U$164: #3V3#2
U$86, U$103, U$165: #SCL#1
U$87, U$104, U$166: #SDA#0
U$88, U$105, U$167: #D_SEL#0

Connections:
3.3V: C2.1, C3.1, C4.1, C5.2, C7.2, C10.1, C11.1, C13.1, C14.1, C16.1, C19.1, C28.1, J1.4, J2.1, J4.2, J12.4, J13.2, J17.2, J19.4, R13.2, R15.2, R20.2, R34.2, U1.16, U2.5, U3.33, U3.34, U3.38, U5.2, U6.4, U6.16, U13.2, U13.3, U13.9, U13.10
3.3V1: C24.1, C25.2, C29.1, C30.2, C33.1, C34.1, C36.1, C37.1, C38.1, C42.1, C46.1, C47.1, J16.2, J25.1, J27.4, J28.4, J31.2, J32.2, J36.4, R12.2, R32.2, R41.2, R55.2, U8.5, U9.33, U9.34, U9.38, U11.4, U11.16, U16.16, U17.2, U17.3, U17.9, U17.10, U18.2
3.3V2: C49.1, C50.2, C53.1, C54.2, C57.1, C58.1, C60.1, C61.1, C62.1, C66.1, C70.1, C71.1, J37.2, J43.1, J45.4, J46.4, J49.2, J50.2, J54.4, R60.2, R64.2, R69.2, R83.2, U19.5, U20.33, U20.34, U20.38, U21.4, U21.16, U25.16, U26.2, U26.3, U26.9, U26.10, U27.2
ANT_VCC: C1.1, FB1.2, R14.1
ANT_VCC1: C27.1, FB2.2, R11.1
ANT_VCC2: C52.1, FB3.2, R59.1
CC1: J5.A5, R17.2
CC2: J5.B5, R16.2
CC3: J3.B5, R37.2
CC4: J3.A5, R38.2
CC5: J20.A5, R21.2
CC6: J20.B5, R18.2
CC7: J23.B5, R39.2
CC8: J23.A5, R40.2
CC9: J38.A5, R62.2
CC10: J38.B5, R61.2
CC11: J41.B5, R67.2
CC12: J41.A5, R68.2
CHG_LED: R1.2, U10.3
CHG_LED1: R42.2, U15.3
CHG_LED2: R70.2, U24.3
CHG_LED_RES: J7.2, JP2.2, R1.1
CHG_LED_RES1: J34.2, JP8.2, R42.1
CHG_LED_RES2: J52.2, JP14.2, R70.1
CHG_THERM1: R5.2, R6.2, R30.2
CHG_THERM2: R43.2, R44.2, R56.2
CHG_THERM3: R71.2, R72.2, R84.2
D+: D6.4, R27.1
D+1: D2.4, U6.5
D+2: D4.4, R8.1
D+3: D11.4, U11.5
D+4: D15.4, R57.1
D+5: D18.4, U21.5
D-: D6.6, R28.1
D-1: D2.6, U6.6
D-2: D4.6, R10.1
D-3: D11.6, U11.6
D-4: D15.6, R58.1
D-5: D18.6, U21.6
ESP32_!DTR: Q2.1, R23.1, U6.13
ESP32_!DTR1: Q3.1, R35.1, U11.13
ESP32_!DTR2: Q5.1, R65.1, U21.13
ESP32_!RTS: Q2.4, R29.1, U6.14
ESP32_!RTS1: Q3.4, R36.1, U11.14
ESP32_!RTS2: Q5.4, R66.1, U21.14
ESP32_EN: C12.1, J14.1, Q2.3, R20.1, U5.3
ESP32_EN1: C35.1, J30.1, Q3.3, R32.1, U18.3
ESP32_EN2: C59.1, J48.1, Q5.3, R64.1, U27.3
ESP32_RXI: U5.34, U6.2
ESP32_RXI1: U11.2, U18.34
ESP32_RXI2: U21.2, U27.34
ESP32_TXO: U5.35, U6.3
ESP32_TXO1: U11.3, U18.35
ESP32_TXO2: U21.3, U27.35
ESP_0/BOOT: Q2.6, U5.25
ESP_0/BOOT1: Q3.6, U18.25
ESP_0/BOOT2: Q5.6, U27.25
ESP_2/MUX_A: U1.10, U5.24
ESP_2/MUX_A1: U16.10, U18.24
ESP_2/MUX_A2: U25.10, U27.24
ESP_4/ACCEL_INT: J18.1, JP1.1, U13.12
ESP_4/ACCEL_INT1: J35.1, JP7.1, U17.12
ESP_4/ACCEL_INT2: J53.1, JP13.1, U26.12
ESP_4/MUX_B: U1.9, U5.26
ESP_4/MUX_B1: U16.9, U18.26
ESP_4/MUX_B2: U25.9, U27.26
ESP_13/POWER_CTRL: D1.A, R22.1, R24.2, U5.16
ESP_13/POWER_CTRL1: D12.A, R50.1, R51.2, U18.16
ESP_13/POWER_CTRL2: D19.A, R78.1, R79.2, U27.16
ESP_14/SETUP_BUTTON: C21.1, J7.3, JP2.4, U5.13
ESP_14/SETUP_BUTTON1: C48.1, J34.3, JP8.4, U18.13
ESP_14/SETUP_BUTTON2: C72.1, J52.3, JP14.4, U27.13
ESP_18/SCK: J19.5, U5.30
ESP_18/SCK1: J36.5, U18.30
ESP_18/SCK2: J54.5, U27.30
ESP_19/CIPO: J19.7, U5.31
ESP_19/CIPO1: J36.7, U18.31
ESP_19/CIPO2: J54.7, U27.31
ESP_21/SDA: J4.3, J13.3, J17.3, R2.P7, U1.2, U5.33, U7.8, U13.4
ESP_21/SDA1: J16.3, J31.3, J32.3, R47.P7, U12.8, U16.2, U17.4, U18.33
ESP_21/SDA2: J37.3, J49.3, J50.3, R75.P7, U22.8, U25.2, U26.4, U27.33
ESP_22/SCL: J4.4, J13.4, J17.4, R2.P8, U1.15, U5.36, U7.7, U13.1
ESP_22/SCL1: J16.4, J31.4, J32.4, R47.P8, U12.7, U16.15, U17.1, U18.36
ESP_22/SCL2: J37.4, J49.4, J50.4, R75.P8, U22.7, U25.15, U26.1, U27.36
ESP_23/COPI: J19.3, U5.37
ESP_23/COPI1: J36.3, U18.37
ESP_23/COPI2: J54.3, U27.37
ESP_25/SD_!CS!: J19.2, R13.1, U5.10
ESP_25/SD_!CS!1: J36.2, R41.1, U18.10
ESP_25/SD_!CS!2: J54.2, R69.1, U27.10
ESP_26/DAC1: U16.11, U18.11
ESP_26/DAC2: U1.11, U5.11
ESP_26/DAC3: U25.11, U27.11
ESP_26/ZED_TX_READY_LV: R3.P4, U3.46
ESP_26/ZED_TX_READY_LV1: R48.P4, U9.46
ESP_26/ZED_TX_READY_LV2: R76.P4, U20.46
ESP_27/FAST_OFF: C20.2, Q1.G1, R24.1, U5.12
ESP_27/FAST_OFF1: C43.2, Q4.G1, R51.1, U18.12
ESP_27/FAST_OFF2: C67.2, Q6.G1, R79.1, U27.12
ESP_D1+: D2.3, J3.A6, J3.B6
ESP_D1+1: D11.3, J23.A6, J23.B6
ESP_D1+2: D18.3, J41.A6, J41.B6
ESP_D1-: D2.1, J3.A7, J3.B7
ESP_D1-1: D11.1, J23.A7, J23.B7
ESP_D1-2: D18.1, J41.A7, J41.B7
ESP_I16/ZED-TXO1: J15.1, R2.P5, U1.12, U5.27
ESP_I16/ZED-TXO2: J29.1, R47.P5, U16.12, U18.27
ESP_I16/ZED-TXO3: J47.1, R75.P5, U25.12, U27.27
ESP_I34/ZED_TX_READY: J6.1, R3.P5, U5.6
ESP_I34/ZED_TX_READY1: J33.1, R48.P5, U18.6
ESP_I34/ZED_TX_READY2: J51.1, R76.P5, U27.6
ESP_I35/DEVICE_SENSE: R33.2, R34.1, U5.7
ESP_I35/DEVICE_SENSE1: R54.2, R55.1, U18.7
ESP_I35/DEVICE_SENSE2: R82.2, R83.1, U27.7
ESP_I39/ADC1: U16.4, U18.5
ESP_I39/ADC2: U25.4, U27.5
ESP_I39/ADC39: U1.4, U5.5
ESP_O17/ZED-RXI1: J15.2, R2.P6, R19.2, U1.1
ESP_O17/ZED-RXI2: J29.2, R45.2, R47.P6, U16.1
ESP_O17/ZED-RXI3: J47.2, R73.2, R75.P6, U25.1
EXTERNAL_DATA_IN: J2.3, J12.2, U1.3
EXTERNAL_DATA_IN1: J25.3, J27.2, U16.3
EXTERNAL_DATA_IN2: J43.3, J45.2, U25.3
EXTERNAL_DATA_OUT: J2.2, J12.3, U1.13
EXTERNAL_DATA_OUT1: J25.2, J27.3, U16.13
EXTERNAL_DATA_OUT2: J43.2, J45.3, U25.13
EXTINT_LV: R9.P2, U3.51
EXTINT_LV1: R49.P2, U9.51
EXTINT_LV2: R77.P2, U20.51
FENCE_LV: R4.P4, U3.19
FENCE_LV1: R46.P4, U9.19
FENCE_LV2: R74.P4, U20.19
GND: C1.2, C2.2, C3.2, C4.2, C5.1, C6.2, C7.1, C8.2, C9.2, C10.2, C11.2, C12.2, C13.2, C14.2, C15.2, C16.2, C17.2, C18.2, C19.2, C21.2, C28.2, D2.2, D6.2, D10.2, E1.GND@0, E1.GND@1, E1.GND@2, E1.GND@3, J1.1, J2.4, J3.GND, J3.GND2, J3.SHLD1, J3.SHLD2, J3.SHLD3, J3.SHLD4, J4.1, J5.GND, J5.GND2, J5.SHLD1, J5.SHLD2, J5.SHLD3, J5.SHLD4, J7.1, J8.1, J9.4, J10.2, J11.1, J12.1, J13.1, J14.2, J17.1, J19.6, J19.9, J19.10, J19.11, J19.12, J19.13, JP2.6, Q1.S1, R6.1, R7.1, R15.1, R16.1, R17.1, R30.1, R33.1, R37.1, R38.1, S1.3, U1.6, U1.7, U1.8, U2.2, U3.1, U3.3, U3.12, U3.14, U3.32, U3.37, U3.41, U3.48, U3.55, U3.56, U3.57, U3.58, U3.59, U3.60, U3.61, U3.62, U3.63, U3.64, U3.65, U3.66, U3.67, U3.68, U3.69, U3.70, U3.71, U3.72, U3.73, U3.74, U3.75, U3.76, U3.77, U3.78, U3.79, U3.80, U3.81, U3.82, U3.83, U3.84, U3.85, U3.86, U3.87, U3.88, U3.89, U3.90, U3.91, U3.92, U3.93, U3.94, U3.95, U3.96, U3.97, U3.98, U3.99, U3.100, U3.101, U3.102, U4.2, U5.1, U5.15, U5.38, U5.GND, U5.GNDT1, U5.GNDT2, U5.GNDT3, U5.GNDT4, U5.GNDT5, U5.GNDT6, U5.GNDT7, U5.GNDT8, U6.1, U7.1, U7.4, U7.6, U7.9, U10.5, U10.11, U13.5, U13.6, U13.7, U13.8
GND1: C24.2, C25.1, C26.2, C27.2, C29.2, C30.1, C31.2, C32.2, C33.2, C34.2, C35.2, C36.2, C37.2, C38.2, C39.2, C40.2, C41.2, C42.2, C46.2, C47.2, C48.2, D4.2, D11.2, D14.2, E2.GND@0, E2.GND@1, E2.GND@2, E2.GND@3, J16.1, J20.GND, J20.GND2, J20.SHLD1, J20.SHLD2, J20.SHLD3, J20.SHLD4, J21.1, J22.2, J23.GND, J23.GND2, J23.SHLD1, J23.SHLD2, J23.SHLD3, J23.SHLD4, J24.4, J25.4, J26.1, J27.1, J28.1, J30.2, J31.1, J32.1, J34.1, J36.6, J36.9, J36.10, J36.11, J36.12, J36.13, JP8.6, Q4.S1, R12.1, R18.1, R21.1, R25.1, R39.1, R40.1, R43.1, R54.1, R56.1, S2.3, U8.2, U9.1, U9.3, U9.12, U9.14, U9.32, U9.37, U9.41, U9.48, U9.55, U9.56, U9.57, U9.58, U9.59, U9.60, U9.61, U9.62, U9.63, U9.64, U9.65, U9.66, U9.67, U9.68, U9.69, U9.70, U9.71, U9.72, U9.73, U9.74, U9.75, U9.76, U9.77, U9.78, U9.79, U9.80, U9.81, U9.82, U9.83, U9.84, U9.85, U9.86, U9.87, U9.88, U9.89, U9.90, U9.91, U9.92, U9.93, U9.94, U9.95, U9.96, U9.97, U9.98, U9.99, U9.100, U9.101, U9.102, U11.1, U12.1, U12.4, U12.6, U12.9, U14.2, U15.5, U15.11, U16.6, U16.7, U16.8, U17.5, U17.6, U17.7, U17.8, U18.1, U18.15, U18.38, U18.GND, U18.GNDT1, U18.GNDT2, U18.GNDT3, U18.GNDT4, U18.GNDT5, U18.GNDT6, U18.GNDT7, U18.GNDT8
GND2: C49.2, C50.1, C51.2, C52.2, C53.2, C54.1, C55.2, C56.2, C57.2, C58.2, C59.2, C60.2, C61.2, C62.2, C63.2, C64.2, C65.2, C66.2, C70.2, C71.2, C72.2, D15.2, D18.2, D21.2, E3.GND@0, E3.GND@1, E3.GND@2, E3.GND@3, J37.1, J38.GND, J38.GND2, J38.SHLD1, J38.SHLD2, J38.SHLD3, J38.SHLD4, J39.1, J40.2, J41.GND, J41.GND2, J41.SHLD1, J41.SHLD2, J41.SHLD3, J41.SHLD4, J42.4, J43.4, J44.1, J45.1, J46.1, J48.2, J49.1, J50.1, J52.1, J54.6, J54.9, J54.10, J54.11, J54.12, J54.13, JP14.6, Q6.S1, R60.1, R61.1, R62.1, R63.1, R67.1, R68.1, R71.1, R82.1, R84.1, S3.3, U19.2, U20.1, U20.3, U20.12, U20.14, U20.32, U20.37, U20.41, U20.48, U20.55, U20.56, U20.57, U20.58, U20.59, U20.60, U20.61, U20.62, U20.63, U20.64, U20.65, U20.66, U20.67, U20.68, U20.69, U20.70, U20.71, U20.72, U20.73, U20.74, U20.75, U20.76, U20.77, U20.78, U20.79, U20.80, U20.81, U20.82, U20.83, U20.84, U20.85, U20.86, U20.87, U20.88, U20.89, U20.90, U20.91, U20.92, U20.93, U20.94, U20.95, U20.96, U20.97, U20.98, U20.99, U20.100, U20.101, U20.102, U21.1, U22.1, U22.4, U22.6, U22.9, U23.2, U24.5, U24.11, U25.6, U25.7, U25.8, U26.5, U26.6, U26.7, U26.8, U27.1, U27.15, U27.38, U27.GND, U27.GNDT1, U27.GNDT2, U27.GNDT3, U27.GNDT4, U27.GNDT5, U27.GNDT6, U27.GNDT7, U27.GNDT8
GPS_ANT1: D10.1, E1.SIG, FB1.1, U3.2
GPS_ANT2: D14.1, E2.SIG, FB2.1, U9.2
GPS_ANT3: D21.1, E3.SIG, FB3.1, U20.2
LIPO_RAW: J8.2, MEAS1.1, MEAS1.3
LIPO_RAW1: J21.2, MEAS3.1, MEAS3.3
LIPO_RAW2: J39.2, MEAS5.1, MEAS5.3
unnamed: R8.2, U9.40
unnamed: R10.2, U9.39
unnamed: R11.2, U9.7
unnamed: J5.VBUS1, J5.VBUS2, MEAS.1, MEAS.3
unnamed: R5.1, U10.8
unnamed: R19.1, U5.28
unnamed: Q3.5, R35.2
unnamed: Q3.2, R36.2
unnamed: D8.A, J23.VBUS1, J23.VBUS2
unnamed: J20.VBUS1, J20.VBUS2, MEAS2.1, MEAS2.3
unnamed: R27.2, U3.40
unnamed: R28.2, U3.39
unnamed: R14.2, U3.7
unnamed: R44.1, U15.8
unnamed: C22.1, C23.2, Q1.D1, Q1.G2, R26.1
unnamed: R45.1, U18.28
unnamed: C44.1, C45.2, Q4.D1, Q4.G2, R52.1
unnamed: R57.2, U20.40
unnamed: R58.2, U20.39
unnamed: R59.2, U20.7
unnamed: Q5.5, R65.2
unnamed: Q5.2, R66.2
unnamed: D17.A, J41.VBUS1, J41.VBUS2
unnamed: Q2.5, R23.2
unnamed: Q2.2, R29.2
unnamed: J38.VBUS1, J38.VBUS2, MEAS4.1, MEAS4.3
unnamed: R72.1, U24.8
unnamed: R73.1, U27.28
unnamed: C68.1, C69.2, Q6.D1, Q6.G2, R80.1
unnamed: D9.A, J3.VBUS1, J3.VBUS2
POWER_BTN: C23.1, D1.C, J7.4, JP1.2, JP2.5, R31.1, S1.1
POWER_BTN1: C45.1, D12.C, J34.4, JP7.2, JP8.5, R53.1, S2.1
POWER_BTN2: C69.1, D19.C, J52.4, JP13.2, JP14.5, R81.1, S3.1
PPS: R9.P1, U3.53
PPS1: R49.P1, U9.53
PPS2: R77.P1, U20.53
PROG1: R7.2, U10.6
PROG2: R25.2, U15.6
PROG3: R63.2, U24.6
RTK_LV: R4.P3, U3.20
RTK_LV1: R46.P3, U9.20
RTK_LV2: R74.P3, U20.20
RX2_LV: R4.P2, U3.26
RX2_LV1: R46.P2, U9.26
RX2_LV2: R74.P2, U20.26
RXLV: R2.P3, U3.43
RXLV1: R47.P3, U9.43
RXLV2: R75.P3, U20.43
SCL_LV: R2.P1, U3.45
SCL_LV1: R47.P1, U9.45
SCL_LV2: R75.P1, U20.45
SDA_LV: R2.P2, U3.44
SDA_LV1: R47.P2, U9.44
SDA_LV2: R75.P2, U20.44
TX2_LV: R4.P1, U3.27
TX2_LV1: R46.P1, U9.27
TX2_LV2: R74.P1, U20.27
TXLV: R2.P4, U3.42
TXLV1: R47.P4, U9.42
TXLV2: R75.P4, U20.42
UNP_D+: D6.3, J5.A6, J5.B6
UNP_D+1: D4.3, J20.A6, J20.B6
UNP_D+2: D15.3, J38.A6, J38.B6
UNP_D-: D6.1, J5.A7, J5.B7
UNP_D-1: D4.1, J20.A7, J20.B7
UNP_D-2: D15.1, J38.A7, J38.B7
VOUT: C6.1, C20.1, J9.1, J11.4, Q1.D2, R22.2, U2.1, U2.3
VOUT1: C26.1, C43.1, J24.1, J26.4, Q4.D2, R50.2, U8.1, U8.3
VOUT2: C51.1, C67.1, J42.1, J44.4, Q6.D2, R78.2, U19.1, U19.3
V_BATT: C8.1, C15.1, C17.1, D7.A, J10.1, MEAS1.2, MEAS1.4, U4.1, U4.3, U7.2, U7.3, U10.9, U10.10
V_BATT1: C31.1, C39.1, C40.1, D5.A, J22.1, MEAS3.2, MEAS3.4, U12.2, U12.3, U14.1, U14.3, U15.9, U15.10
V_BATT2: C55.1, C63.1, C64.1, D16.A, J40.1, MEAS5.2, MEAS5.4, U22.2, U22.3, U23.1, U23.3, U24.9, U24.10
V_BKCP: C18.1, U3.36, U4.5
V_BKCP1: C41.1, U9.36, U14.5
V_BKCP2: C65.1, U20.36, U23.5
V_RAW: C9.1, C22.2, D3.C, D7.C, Q1.S2, R26.2, R31.2, U10.1, U10.2
V_RAW1: C32.1, C44.2, D5.C, D13.C, Q4.S2, R52.2, R53.2, U15.1, U15.2
V_RAW2: C56.1, C68.2, D16.C, D20.C, Q6.S2, R80.2, R81.2, U24.1, U24.2
V_USB: D2.5, D3.A, D6.5, D9.C, JP2.1, MEAS.2, MEAS.4
V_USB1: D4.5, D8.C, D11.5, D13.A, JP8.1, MEAS2.2, MEAS2.4
V_USB2: D15.5, D17.C, D18.5, D20.A, JP14.1, MEAS4.2, MEAS4.4
ZED-RXI1: J24.3, J26.2, R46.P7
ZED-RXI2: J9.3, J11.2, R4.P7
ZED-RXI3: J42.3, J44.2, R74.P7
ZED-TXO1: J24.2, J26.3, R46.P8
ZED-TXO2: J9.2, J11.3, R4.P8
ZED-TXO3: J42.2, J44.3, R74.P8
ZED_!RESET!: J6.3, R3.P7
ZED_!RESET!1: J33.3, R48.P7
ZED_!RESET!2: J51.3, R76.P7
ZED_!RESET!_LV: R3.P2, U3.49
ZED_!RESET!_LV1: R48.P2, U9.49
ZED_!RESET!_LV2: R76.P2, U20.49
ZED_!SAFE!: J6.4, R3.P8
ZED_!SAFE!1: J33.4, R48.P8
ZED_!SAFE!2: J51.4, R76.P8
ZED_!SAFE!_LV: R3.P1, U3.50
ZED_!SAFE!_LV1: R48.P1, U9.50
ZED_!SAFE!_LV2: R76.P1, U20.50
ZED_D_SEL: J6.2, R3.P6
ZED_D_SEL1: J33.2, R48.P6
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

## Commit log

2021-02-24 Add firmware
    [Button LED Layout RTK Express.sch, ESP32_RF_INIT.xlsx, ESP8266_RF_init.xls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]
2021-02-24 Control base/rover state based on power button tap
2021-03-04 Ready v11. Redo GND layers for panelizer.
    [SparkFun RTK Express-Panel.GBL, SparkFun RTK Express-Panel.GBO, SparkFun RTK Express-Panel.GBP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]
2021-03-04 Add helper displays for base/rover switching.
2021-03-04 Update Button LED Layout RTK Express.sch
    [Button LED Layout RTK Express.sch]
2021-03-19 Update FP and PROD ID on ESP32 module
    [SparkFun RTK Express.brd, SparkFun RTK Express.sch]
2021-04-16 Move radio to power control. Add ESD to GNSS RF. Move overlay connector.
    [SparkFun RTK Express.brd, SparkFun RTK Express.sch]
2021-04-16 Add BT pin support. Add accel support. Increase xTask sizes. Increase I2C to 400kHz.
2021-04-16 Update v12 panel files.
    [SparkFun RTK Express-Panel.brd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]
2021-04-16 Update panel file to v12
    [SparkFun RTK Express-Panel.brd]
2021-04-16 Add PROD_ID for PESD diode.
    [SparkFun RTK Express.brd, SparkFun RTK Express.sch]
2021-06-01 Add test sketches
    [Example_Config.txt, Example_Config1.txt]
2021-06-01 Shuffle schematic elements to fit into frame.
    [SparkFun RTK Express.brd, SparkFun RTK Express.sch]
2021-06-09 Removing redundant firmware files.
    For RTK Firmware see: https://github.com/sparkfun/SparkFun_RTK_Firmware
    [1553B-1.igs, 1553B-1.stp, ESP32_RF_INIT.xlsx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]
2021-06-17 Move to non-SMD SMA. Change to push-push microSD.
    [SparkFun RTK Express.GBL, SparkFun RTK Express.GBO, SparkFun RTK Express.GBP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]
2021-06-17 Move microSD socket further out.
    [SparkFun RTK Express.brd, SparkFun RTK Express.sch]
2021-07-01 Remove push pull SD socket. v13 PCB
    [SparkFun RTK Express.brd, SparkFun RTK Express.sch]
2021-07-01 v13 PCB. Add panel. Change from SMD SMA To edge mount SMD to increase strength of connector.
    [SparkFun RTK Express-Panel.brd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]
2021-07-01 Remove old single board test files
    [SparkFun RTK Express.GBL, SparkFun RTK Express.GBO, SparkFun RTK Express.GBP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]
2022-02-03 Remove graphics (moved to Firmware repo)
    [SparkFun RTK Express.sch]
2022-02-24 v14 - Remove ground plane from around accelerometer
    [SparkFun RTK Express-Panel.brd, SparkFun RTK Express.brd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]
2022-03-07 Remove groundplane from around accel. Switch to wider ESP FP, exposed pin microSD, CH340 with VCC from USB.
    Increase paste on 12-pin FPC connector.
    [SparkFun RTK Express.brd, SparkFun RTK Express.sch]
2022-03-07 Remove old files
    [SparkFun RTK Express-Panel.GBL, SparkFun RTK Express-Panel.GBO, SparkFun RTK Express-Panel.GBP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]
2022-03-07 New production files for v14 PCB.
    [SparkFun RTK Express-Panel.GBL, SparkFun RTK Express-Panel.GBO, SparkFun RTK Express-Panel.GBP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]
2022-03-07 Add impendence control note
    [SparkFun RTK Express.brd]
2022-03-30 Add route out note
    [SparkFun RTK Express.brd]
2022-04-11 LIF overlay connector, accel plane removal, full ESP32 FP.
    [SparkFun RTK Express-Panel.GBL, SparkFun RTK Express-Panel.GBP, SparkFun RTK Express-Panel.GBS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]
2022-05-18 v15. Fix tCream on LIF connector. Correct CH340 3.3V.
    [SparkFun RTK Express-Panel.brd, SparkFun RTK Express.brd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]
2022-05-18 Production files for v15
    [SparkFun RTK Express-Panel.brd, SparkFun RTK Express.brd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]
2024-12-20 Add enclosure 3D file

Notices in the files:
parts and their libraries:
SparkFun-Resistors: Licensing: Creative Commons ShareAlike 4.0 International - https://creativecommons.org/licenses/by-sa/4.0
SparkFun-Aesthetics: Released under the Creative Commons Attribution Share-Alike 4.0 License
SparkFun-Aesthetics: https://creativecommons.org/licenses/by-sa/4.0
